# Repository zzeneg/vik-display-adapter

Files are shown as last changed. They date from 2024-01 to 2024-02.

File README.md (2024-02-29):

# VIK Bare Display adapter

Small adapter for bare LCD displays to [VIK](https://github.com/sadekbaroudi/vik) connector.

## Features

- horizontal or vertical VIK connector (FPC)
- automatic reset (no separate pin)
- two mounting holes for solder nuts
- testing pads

## Supported displays

Theoretically any display with 12pin welding type FPC with this pin out:

```
- GND
- LEDK
- LEDA
- VDD
- GND
- GND
- DC
- CS
- SCL
- SDA
- RESET
- GND
```

Bare displays can be used with any PCB size, but they are pretty fragile without any support, so be careful.

Existing PCBs for specific sizes:

- 1.28" round display ([example](https://www.aliexpress.com/item/1005006051175539.html))
- universal **0.7mm** pitch / 1.47" rectangular display ([example](https://www.aliexpress.com/item/1005004833011998.html))
- universal **0.8mm** pitch ([example](https://www.aliexpress.com/item/1416043398.html))

## Forced backlight

If controlled backlight is not needed (for example no GPIO2 on VIK), GND testing pad can be bridged to R1 bottom pad, for 100% backlight. In that case S8050 and R1 parts are not needed.

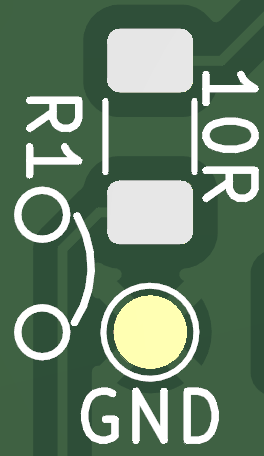
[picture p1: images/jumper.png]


## Photos

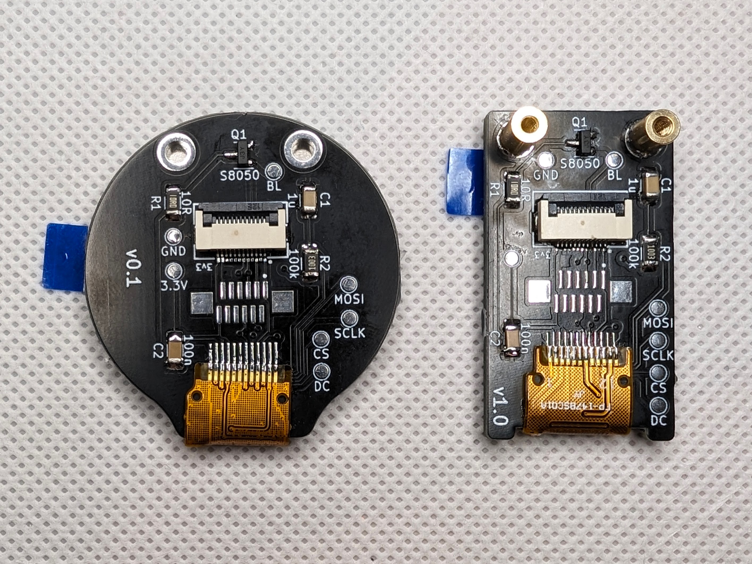
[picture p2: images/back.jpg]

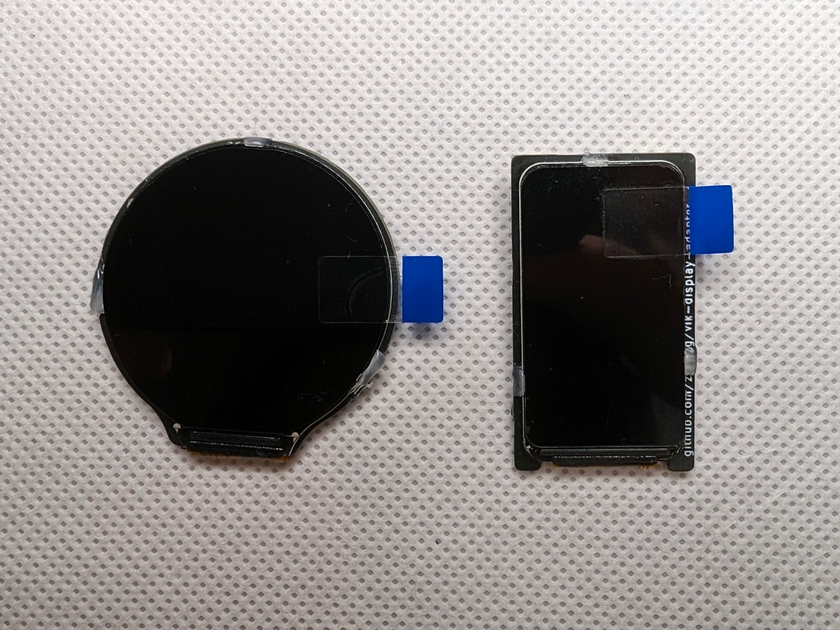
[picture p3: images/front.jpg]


## BOM

All SMD components are 1206 size

- 10R resistor
- 100k resistor
- 1uF capacitor
- 100nF capacitor
- S8050 transistor
- 12pin FFC connector vertical/horizontal (both can be soldered in the same time)

## VIK module certification

| Category | Classification | Response |
| --- | --- | --- |
| FPC connector | Required | :heavy_check_mark: |
| Breakout pins | Recommended | :x: |
| Uses: SPI | Optional | :heavy_check_mark: |
| SPI used for SPI only | Strongly recommended | :heavy_check_mark: |
| Uses: I2C | Optional | :x: |
| I2C used for I2C only | Strongly Recommended | N/A |
| I2C pull ups | Required | N/A |
| Uses: RGB | Optional | :x: |
| Uses: Extra GPIO 1 | Optional | :heavy_check_mark: |
| Uses: Extra GPIO 2 | Optional | :heavy_check_mark: |
| Standard PCB Size/Mount | Strongly recommended | :x: |

## Used projects and resources

- https://www.waveshare.net/w/upload/f/f5/1.47inch_LCD_Module_SchDoc.pdf
- https://hackaday.io/project/168130-universal-ips-display-breakout-board
- 1.47" LCD model https://grabcad.com/library/1-47-rgb-tft-lcd-screen-display-module-172-320-ips-screen-st7789-driver-8pin-1
- 1.28" round LCD model https://grabcad.com/library/1-28-lcd-ga9a01-1

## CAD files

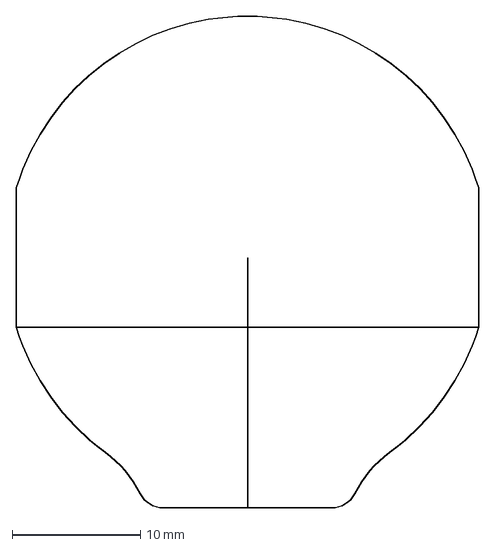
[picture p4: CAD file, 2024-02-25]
pcb/1.28inch-round/outline.dxf
36.0 x 38.3 mm

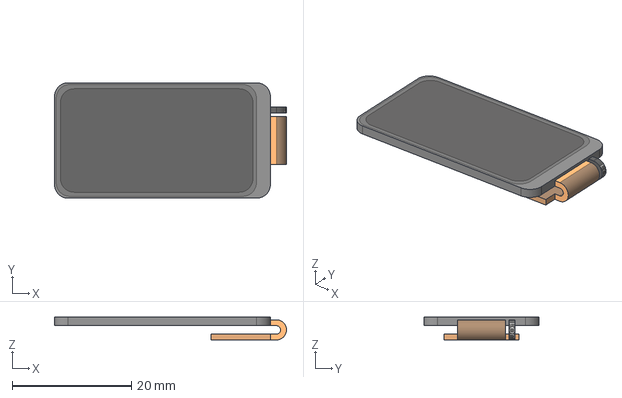
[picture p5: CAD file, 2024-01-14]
pcb/1.47inch/LCD_lcd_ips.stp
39.0 x 19.4 x 3.86 mm

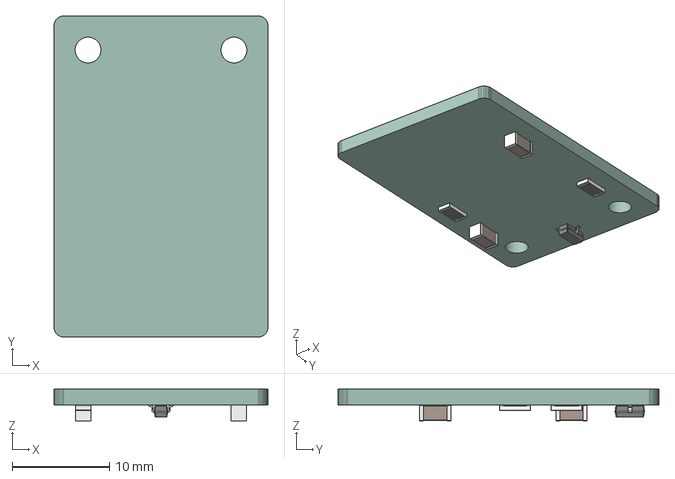
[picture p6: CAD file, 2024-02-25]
pcb/2inch-0.8mm/2inch-0.8mm.step
22.0 x 33.0 x 3.25 mm
_autosave-pcb PCB

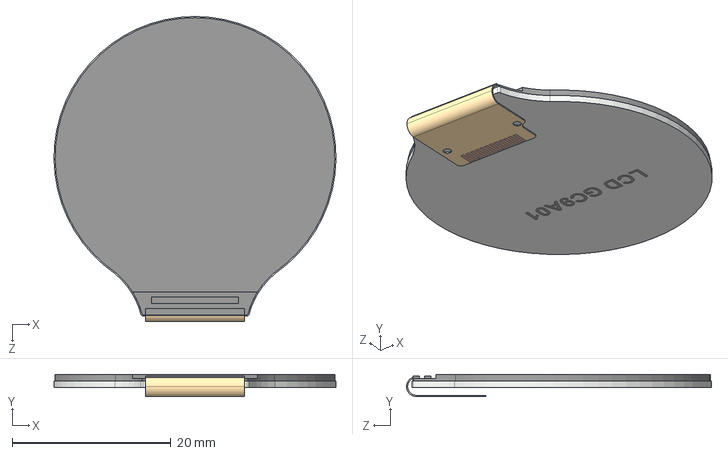
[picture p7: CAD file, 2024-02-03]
pcb/1.28inch-round/GC9A01.STEP
35.5 x 2.77 x 38.4 mm

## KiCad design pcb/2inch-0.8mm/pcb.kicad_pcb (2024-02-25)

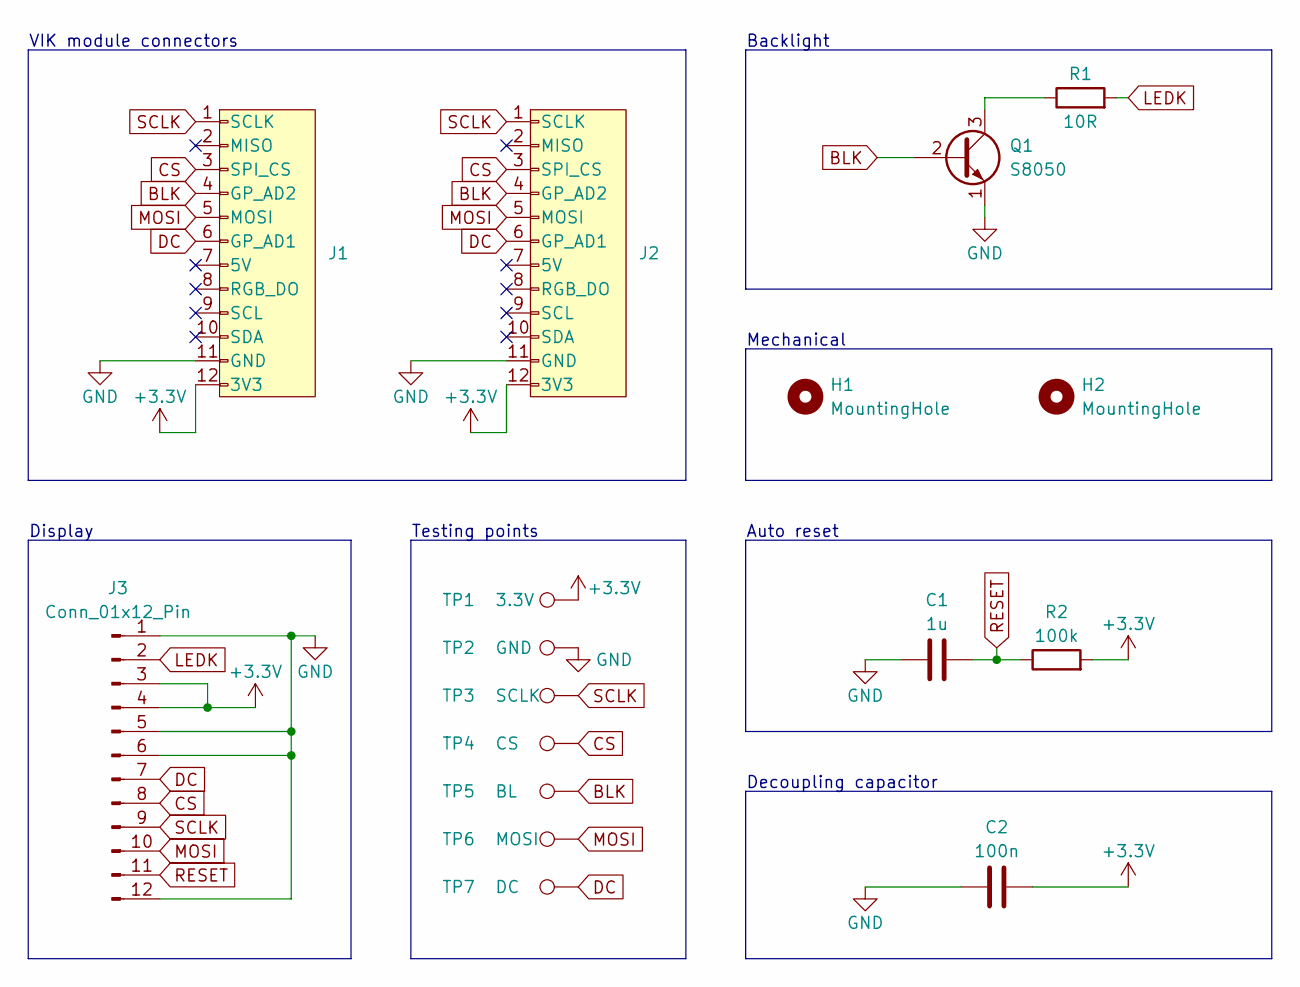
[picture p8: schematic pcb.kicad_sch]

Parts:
C1: 1u; C_1206_3216Metric_Pad1.33x1.80mm_HandSolder
C2: 100n; C_1206_3216Metric_Pad1.33x1.80mm_HandSolder
H1, H2: MountingHole; Hole_M2-solder-nut-2.5
J1: vik-module-connector; vik-module-connector-horizontal
J2: vik-module-connector; Connector_VIK-vertical-module
J3: Conn_01x12_Pin; Connector_Display-12pin-0.8mm
Q1: S8050; Transistor-S8050-SOT-23
R1: 10R; R_1206_3216Metric_Pad1.30x1.75mm_HandSolder
R2: 100k; R_1206_3216Metric_Pad1.30x1.75mm_HandSolder
TP1: 3.3V; TestPoint_Pad_D2.0mm
TP2: GND; TestPoint_Pad_D2.0mm
TP3: SCLK; TestPoint_Pad_D2.0mm
TP4: CS; TestPoint_Pad_D2.0mm
TP5: BL; TestPoint_Pad_D2.0mm
TP6: MOSI; TestPoint_Pad_D2.0mm
TP7: DC; TestPoint_Pad_D2.0mm

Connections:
+3.3V: C2.2, J1.12 (3V3), J2.12 (3V3), J3.3, J3.4, R2.2, TP1.1
BLK: J1.4 (GP_AD2), J2.4 (GP_AD2), Q1.2 (B), TP5.1
CS: J1.3 (SPI_CS), J2.3 (SPI_CS), J3.8, TP4.1
DC: J1.6 (GP_AD1), J2.6 (GP_AD1), J3.7, TP7.1
GND: C1.1, C2.1, J1.11 (GND), J2.11 (GND), J3.1, J3.5, J3.6, J3.12, Q1.1 (E), TP2.1
LEDK: J3.2, R1.2
MOSI: J1.5 (MOSI), J2.5 (MOSI), J3.10, TP6.1
unnamed: Q1.3 (C), R1.1
RESET: C1.2, J3.11, R2.1
SCLK: J1.1 (SCLK), J2.1 (SCLK), J3.9, TP3.1

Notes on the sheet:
Display
Mechanical
Backlight
Auto reset
Decoupling capacitor
Testing points
VIK module connectors

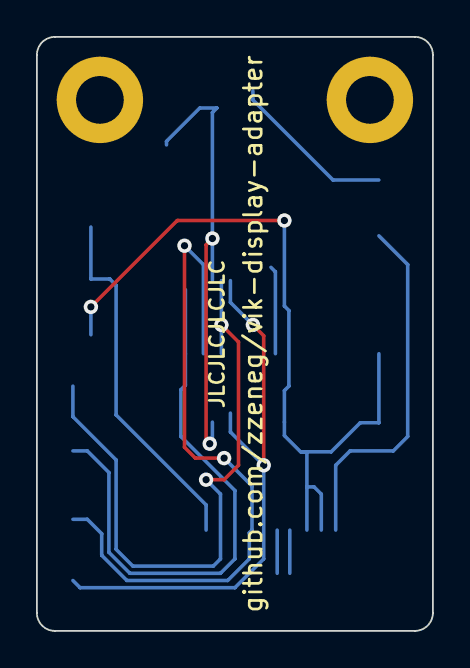
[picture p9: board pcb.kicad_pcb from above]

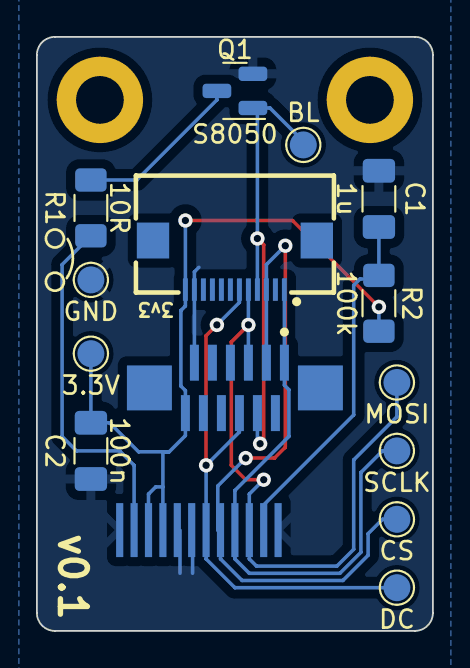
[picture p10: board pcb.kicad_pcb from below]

Board: 2 copper layers, 22.0 x 33.0 mm, 17 parts (17 on the bottom side), 10 nets.

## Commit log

2024-02-03 1.28-round - v0.1
    [GC9A01.STEP, outline.dxf, pcb.kicad_pcb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]
2024-02-09 2inch 0.8mm - v0.1
    [pcb.kicad_pcb, pcb.kicad_sch]
2024-02-25 small updates
    [2inch-0.8mm.step, outline.dxf, pcb.kicad_pcb]
